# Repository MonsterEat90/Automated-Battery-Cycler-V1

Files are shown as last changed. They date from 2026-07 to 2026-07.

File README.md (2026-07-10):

# Automated-Battery-Cycler-V1
This device enabled you to test the endurance of your battery from LiFePO4, Li-On, and Li-Po (1 Cell). The size right now is for 18650 or 26650 battery cell. The load is an IRFZ44N with CC (Constant Current) and CP (Constant Power) mode.
This project is coded with PlatformIO.

Parts needed for this project:
1. ESP32 DevKit V1
2. INA219
3. ADS1115
4. TC4422
5. IRFZ44N
6. Voltage divider (R1 10K R2 10K) with 100nF ceramic cap for filter
7. NTC 10k and R2 10K (act like a Voltage divider) in series with 100nF cap for filter
8. Custom made 2 channel SPDT relay
9. 470uF electrolytic cap
10. 22uF electrolytic cap
11. MicroSD card module

# Schematic

It is best to drive the TC4422 with +12V for better control for the MOSFET and you can still give it PWN straight from the ESP32 pin. You can also change the relay with something more capable.
REMINDER!!!: Change the shunt in the INA219 according to how much current you need or use INA226 for better resolution.

# PCB

This is my PCB. Still quite basic but sufficient enough for this project.

Everything can be change according to your need. Let me know what your thought about this project.

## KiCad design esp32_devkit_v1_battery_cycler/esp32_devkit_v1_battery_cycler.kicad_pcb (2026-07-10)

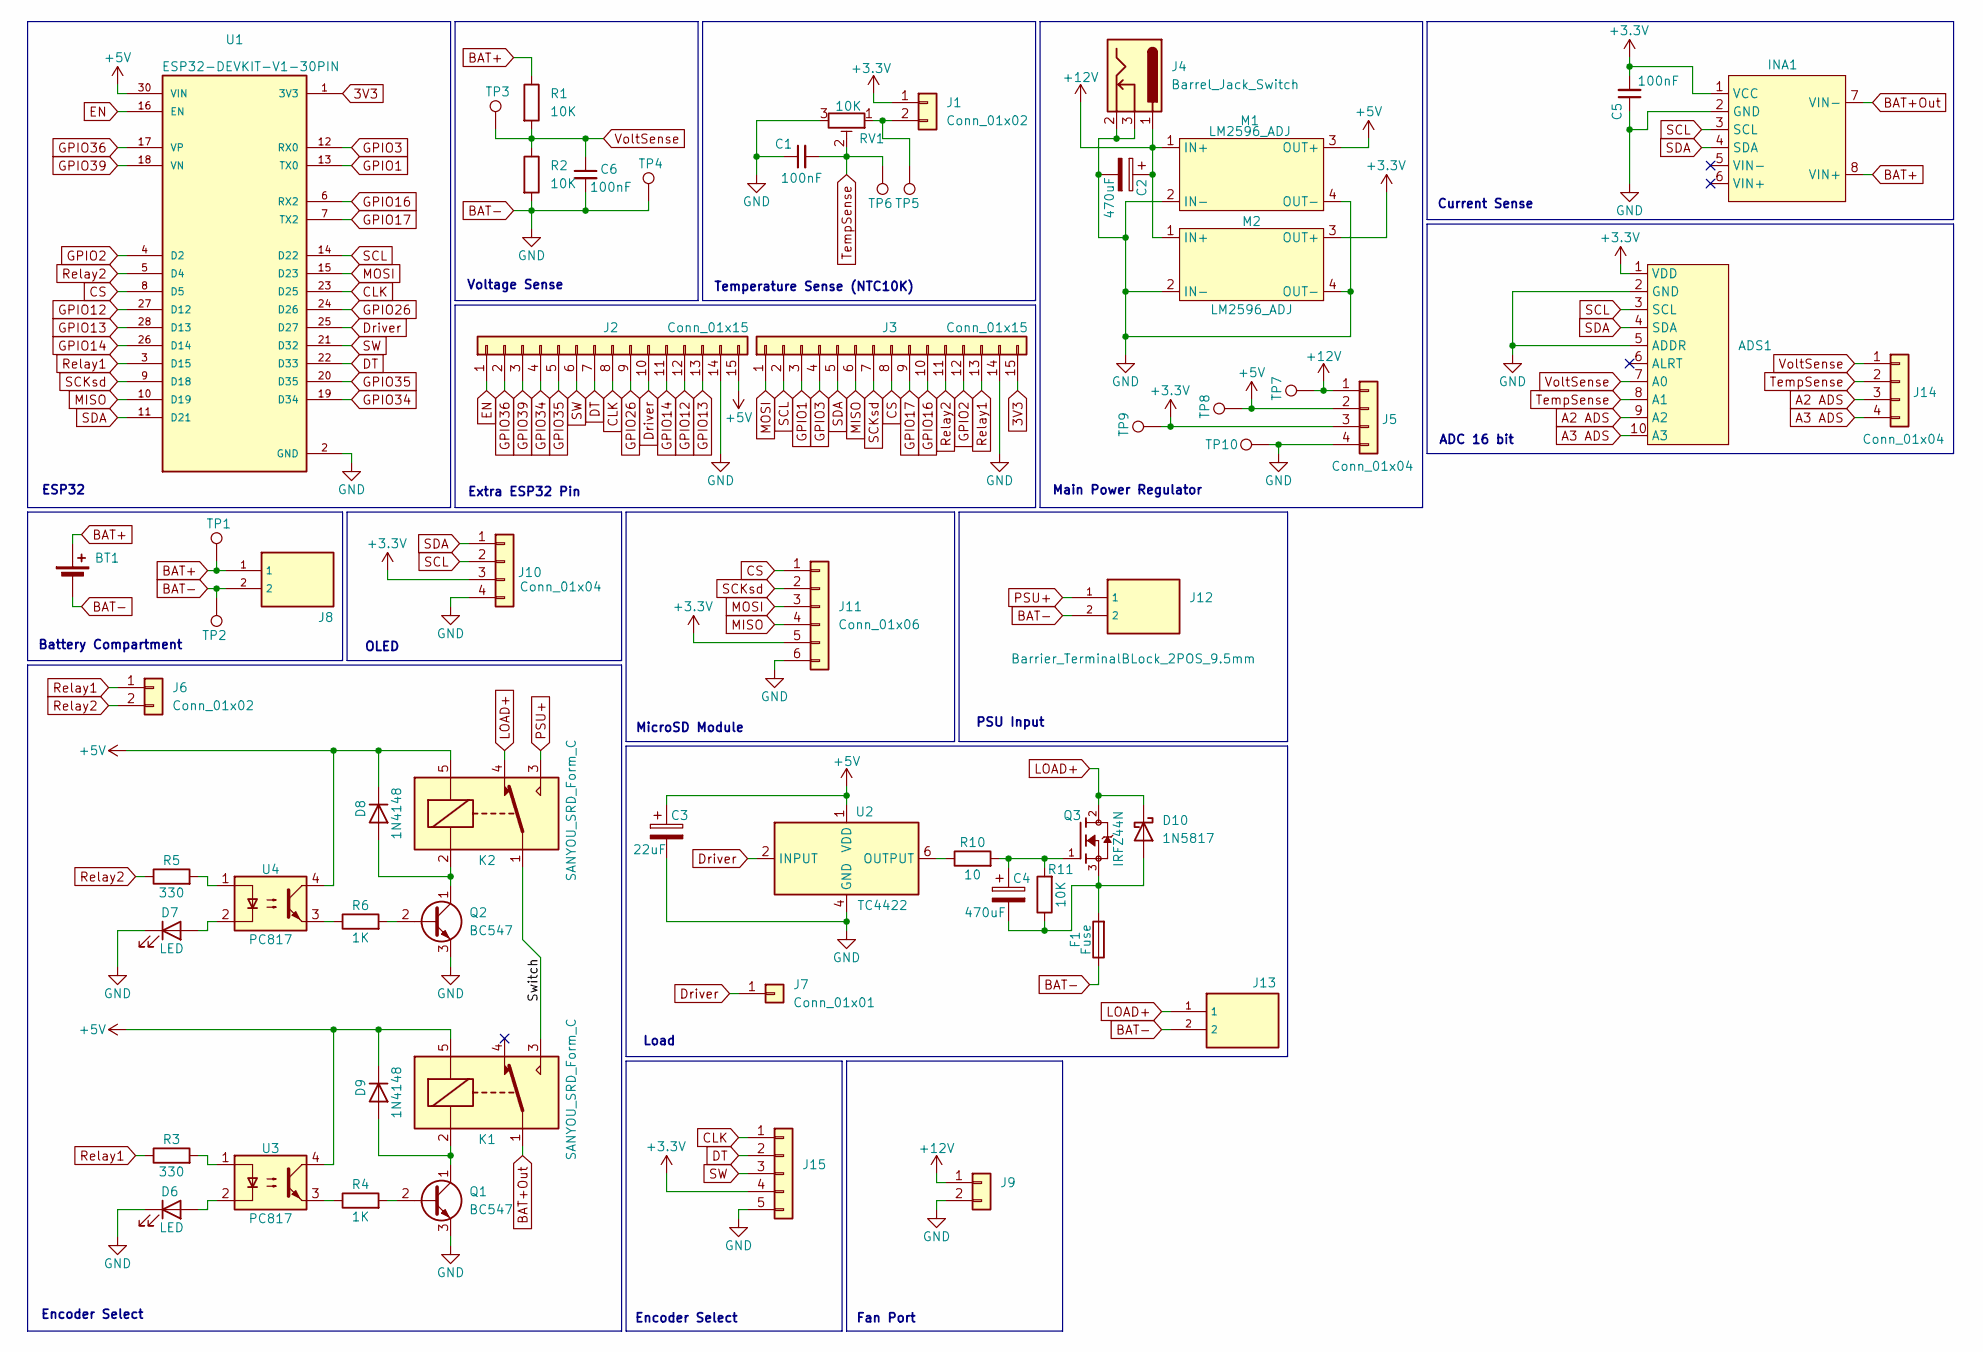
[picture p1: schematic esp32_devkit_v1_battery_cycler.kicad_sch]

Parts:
ADS1: ADS1115
BT1: Battery_Cell; 26650BatteryHolder_THT_RoundPin
C1, C5, C6: 100nF; C_Disc_D5.0mm_W2.5mm_P2.50mm
C2, C4: 470uF; CP_Radial_D8.0mm_P5.00mm
C3: 22uF; CP_Radial_D8.0mm_P5.00mm
D6, D7: LED; LED_D5.0mm
D8, D9: 1N4148; D_DO-35_SOD27_P7.62mm_Horizontal
D10: 1N5817; D_DO-41_SOD81_P10.16mm_Horizontal
F1: Fuse; Fuseholder_Clip-5x20mm_Eaton_1A5601-01_Inline_P20.80x6.76mm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
INA1: INA219
J1, J6, J9: Conn_01x02; PinHeader_1x02_P2.54mm_Vertical
J2, J3: Conn_01x15; PinHeader_1x15_P2.54mm_Vertical
J4: Barrel_Jack_Switch; BarrelJack_Horizontal
J5, J10, J14: Conn_01x04; PinHeader_1x04_P2.54mm_Vertical
J7: Conn_01x01; PinHeader_1x01_P2.54mm_Vertical
J8, J12, J13: Barrier_TerminalBLock_2POS_9.5mm; Barrier_Terminal_Block_2POS_HolePitch9.5mm
J11: Conn_01x06; PinHeader_1x06_P2.54mm_Vertical
J15: Conn_01x05; PinHeader_1x05_P2.54mm_Vertical
K1, K2: SANYOU_SRD_Form_C; Relay_SPDT_SANYOU_SRD_Series_Form_C
M1, M2: LM2596_ADJ; DCDC_StepDown_LM2596
Q1, Q2: BC547; TO-92_Inline
Q3: IRFZ44N; PARTREV 09/21/10
R1, R2: 10K; R_Axial_DIN0309_L9.0mm_D3.2mm_P12.70mm_Horizontal
R3, R5: 330; R_Axial_DIN0207_L6.3mm_D2.5mm_P10.16mm_Horizontal
R4, R6: 1K; R_Axial_DIN0207_L6.3mm_D2.5mm_P10.16mm_Horizontal
R10: 10; R_Axial_DIN0207_L6.3mm_D2.5mm_P10.16mm_Horizontal
R11: 10K; R_Axial_DIN0207_L6.3mm_D2.5mm_P10.16mm_Horizontal
RV1: 10K; Potentiometer_Runtron_RM-065_Vertical
TP1, TP2, TP3, TP4, TP5, TP6, TP7, TP8, TP9, TP10: TestPoint; TestPoint_Pad_D2.0mm
U1: ESP32-DEVKIT-V1-30PIN; ESP32DEVKITv1_30pin; PARTREV N/A
U2: TC4422; DIP-8_W7.62mm
U3, U4: PC817; DIP-4_W7.62mm

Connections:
3V3: J3.15, U1.1 (3V3)
+3.3V: ADS1.1 (VDD), C5.2, INA1.1 (VCC), J1.1, J5.3, J10.3, J11.5, J15.4, M2.3 (OUT+), TP9.1
+5V: C3.1, D8.1 (K), D9.1 (K), J2.15, J5.2, K1.5, K2.5, M1.3 (OUT+), TP8.1, U1.30 (VIN), U2.1 (VDD), U2.8 (VDD), U3.4, U4.4
+12V: C2.1, J4.1, J5.1, J9.1, M1.1 (IN+), M2.1 (IN+), TP7.1
/Switch: K1.3, K2.1
A2 ADS: ADS1.9 (A2), J14.3
A3 ADS: ADS1.10 (A3), J14.4
BAT+: BT1.1 (+), INA1.8 (VIN+), J8.1, R1.1, TP1.1
BAT+Out: INA1.7 (VIN-), K1.1
BAT-: ADS1.2 (GND), ADS1.5 (ADDR), BT1.2 (-), C1.1, C2.2, C3.2, C5.1, C6.2, D6.1 (K), D7.1 (K), F1.1, INA1.2 (GND), J2.14, J3.14, J4.2, J4.3, J5.4, J8.2, J9.2, J10.4, J11.6, J12.2, J13.2, J15.5, M1.2 (IN-), M1.4 (OUT-), M2.2 (IN-), M2.4 (OUT-), Q1.3 (E), Q2.3 (E), R2.2, RV1.3, TP2.1, TP4.1, TP10.1, U1.2 (GND), U1.29 (GND), U2.4 (GND), U2.5 (GND)
CLK: J2.8, J15.1, U1.23 (D25)
CS: J3.8, J11.1, U1.8 (D5)
DT: J2.7, J15.2, U1.22 (D33)
Driver: J2.10, J7.1, U1.25 (D27), U2.2 (INPUT)
EN: J2.1, U1.16 (EN)
GPIO1: J3.3, U1.13 (TX0)
GPIO2: J3.12, U1.4 (D2)
GPIO3: J3.4, U1.12 (RX0)
GPIO12: J2.12, U1.27 (D12)
GPIO13: J2.13, U1.28 (D13)
GPIO14: J2.11, U1.26 (D14)
GPIO16: J3.10, U1.6 (RX2)
GPIO17: J3.9, U1.7 (TX2)
GPIO26: J2.9, U1.24 (D26)
GPIO34: J2.4, U1.19 (D34)
GPIO35: J2.5, U1.20 (D35)
GPIO36: J2.2, U1.17 (VP)
GPIO39: J2.3, U1.18 (VN)
LOAD+: D10.1 (K), J13.1, K2.4, Q3.2
MISO: J3.6, J11.4, U1.10 (D19)
MOSI: J3.1, J11.3, U1.15 (D23)
unnamed: C4.1, Q3.1, R10.2, R11.2
unnamed: D6.2 (A), U3.2
unnamed: D7.2 (A), U4.2
unnamed: D8.2 (A), K2.2, Q2.1 (C)
unnamed: D9.2 (A), K1.2, Q1.1 (C)
unnamed: C4.2, D10.2 (A), F1.2, Q3.3, R11.1
unnamed: J1.2, RV1.1, TP5.1
unnamed: Q1.2 (B), R4.2
unnamed: Q2.2 (B), R6.2
unnamed: R3.2, U3.1
unnamed: R4.1, U3.3
unnamed: R5.2, U4.1
unnamed: R6.1, U4.3
unnamed: R10.1, U2.6 (OUTPUT), U2.7 (OUTPUT)
PSU+: J12.1, K2.3
Relay1: J3.13, J6.1, R3.1, U1.3 (D15)
Relay2: J3.11, J6.2, R5.1, U1.5 (D4)
SCKsd: J3.7, J11.2, U1.9 (D18)
SCL: ADS1.3 (SCL), INA1.3 (SCL), J3.2, J10.2, U1.14 (D22)
SDA: ADS1.4 (SDA), INA1.4 (SDA), J3.5, J10.1, U1.11 (D21)
SW: J2.6, J15.3, U1.21 (D32)
TempSense: ADS1.8 (A1), C1.2, J14.2, RV1.2, TP6.1
VoltSense: ADS1.7 (A0), C6.1, J14.1, R1.2, R2.1, TP3.1

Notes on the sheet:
Voltage Sense
OLED
ESP32
Encoder Select
Fan Port
Extra ESP32 Pin
ADC 16 bit
Current Sense
Temperature Sense (NTC10K)
Main Power Regulator
Load
PSU Input
MicroSD Module
Battery Compartment

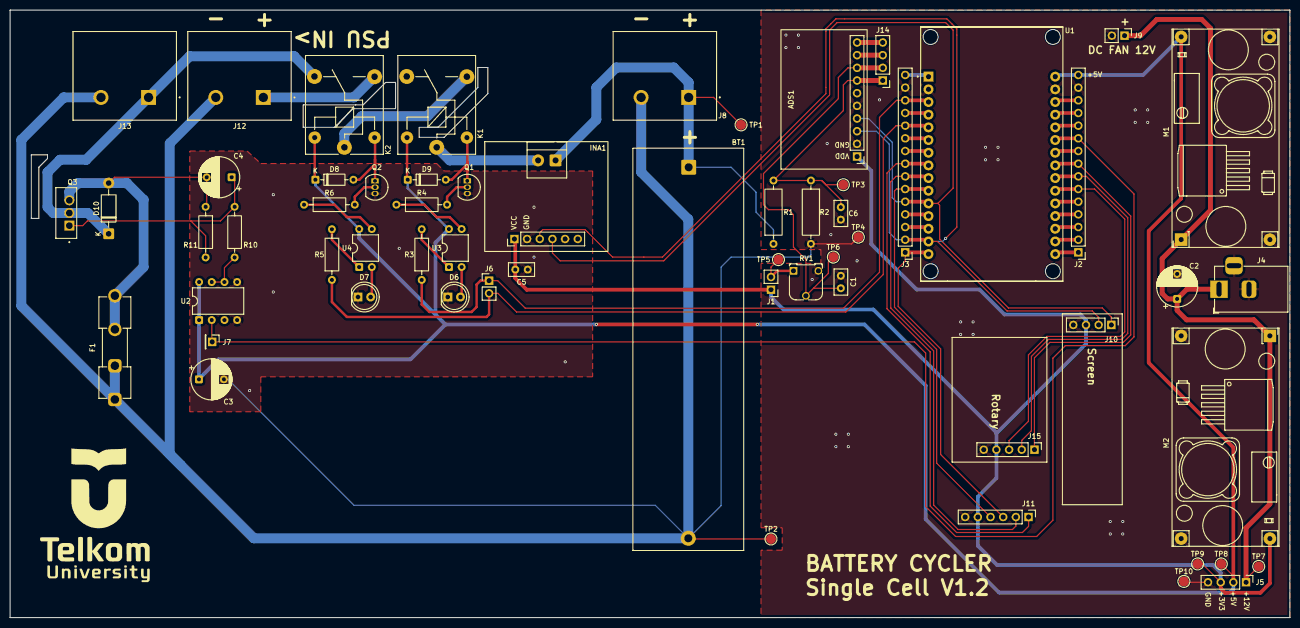
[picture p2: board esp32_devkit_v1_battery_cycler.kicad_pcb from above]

Board: 2 copper layers, 256.5 x 121.8 mm, 60 parts (0 on the bottom side), 54 nets.

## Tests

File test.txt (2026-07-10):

#include "encoder.h"
#include "types.h"

#include <Arduino.h>

#include "config.h"
#include "cycler.h"

static int lastCLK;

static uint8_t selectedItem = 0;

static UiState uiState =
    UiState::NAVIGATE;

void encoderBegin()
{
    pinMode(
        ENC_CLK_PIN,
        INPUT_PULLUP
    );

    pinMode(
        ENC_DT_PIN,
        INPUT_PULLUP
    );

    pinMode(
        ENC_SW_PIN,
        INPUT_PULLUP
    );

    lastCLK =
        digitalRead(
            ENC_CLK_PIN
        );

    Serial.println(
        "[OK] Encoder"
    );
}

static int readRotation()
{
    int movement = 0;

    int clk =
        digitalRead(
            ENC_CLK_PIN
        );

    if(clk != lastCLK)
    {
        if(
            digitalRead(
                ENC_DT_PIN
            ) != clk
        )
        {
            movement = 1;
        }
        else
        {
            movement = -1;
        }

        lastCLK = clk;
    }

    return movement;
}

static bool buttonPressed()
{
    static bool lastState = HIGH;

    bool state =
        digitalRead(
            ENC_SW_PIN
        );

    bool pressed =
        (
            lastState == HIGH &&
            state == LOW
        );

    lastState = state;

    return pressed;
}

void encoderUpdate(
    SystemData& systemData
)
{
    int move =
        readRotation();

    /*
    =====================================
    NAVIGATION MODE
    =====================================
    */

    if(
        uiState ==
        UiState::NAVIGATE
    )
    {
        if(move > 0)
        {
            if(selectedItem < 3)
            {
                selectedItem++;
            }
        }

        if(move < 0)
        {
            if(selectedItem > 0)
            {
                selectedItem--;
            }
        }

        if(buttonPressed())
        {
            if(
                selectedItem ==
                static_cast<uint8_t>(
                    MenuItem::START
                )
            )
            {
                cyclerStart(
                    systemData
                );
            }
            else
            {
                uiState =
                    UiState::EDIT;
            }
        }
    }

    /*
    =====================================
    EDIT MODE
    =====================================
    */

    else
    {
        switch(
            static_cast<MenuItem>(
                selectedItem
            )
        )
        {
            case MenuItem::CYCLE_COUNT:
            {
                systemData.settings.cycleTarget += move;

                systemData.settings.cycleTarget =
                    constrain(
                        systemData.settings.cycleTarget,
                        MIN_CYCLE_COUNT,
                        MAX_CYCLE_COUNT
                    );
                break;
            }

            case MenuItem::MODE:
            {
                if(move != 0)
                {
                    if(
                        systemData.settings.mode ==
                        DischargeMode::CONSTANT_CURRENT
                    )
                    {
                        systemData.settings.mode =
                            DischargeMode::CONSTANT_POWER;
                    }
                    else
                    {
                        systemData.settings.mode =
                            DischargeMode::CONSTANT_CURRENT;
                    }
                }
                break;
            }

            case MenuItem::SETPOINT:
            {
                /*
                Locked in V1

                CC = 3.5A
                CP = 11.2W
                */

                break;
            }

            default:
                break;
        }

        if(buttonPressed())
        {
            uiState =
                UiState::NAVIGATE;
        }
    }
}

uint8_t getSelectedMenu()
{
    return selectedItem;
}

bool isEditing()
{
    return (
        uiState ==
        UiState::EDIT
    );
}

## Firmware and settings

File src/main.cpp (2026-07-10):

#include <Arduino.h>

#include "config.h"
#include "types.h"

#include "sensors.h"
#include "relay.h"
#include "load.h"
#include "controller.h"
#include "cycler.h"
#include "safety.h"
#include "display.h"
#include "encoder.h"
#include "logger.h"

SystemData systemData;

static uint32_t sensorTimer = 0;
static uint32_t controlTimer = 0;
static uint32_t displayTimer = 0;
static uint32_t loggerTimer = 0;

void setup()
{
    Serial.begin(115200);

    Serial.println();
    Serial.println(PROJECT_NAME);
    Serial.println(FW_VERSION);

    /*Hardware*/
    sensorsBegin();
    relayBegin();
    loadBegin();

    /*Logic*/
    controllerBegin();
    cyclerBegin();
    safetyBegin();

    /*UI*/
    displayBegin();
    encoderBegin();

    /*Storage*/
    loggerBegin();

    /*Initial State*/
    systemData.state = CycleState::IDLE;
    systemData.settings.cycleTarget = 1;
    systemData.settings.mode = DischargeMode::CONSTANT_CURRENT;
}

void loop()
{
    uint32_t now = millis();

    if(now - controlTimer >= 20)
    {
        controlTimer = now;

        if(
            systemData.state ==
            CycleState::IDLE
        )
        {
            encoderUpdate(
                systemData
            );
        }
    }

    if(now - sensorTimer >= 100)
    {
        sensorTimer = now;

        sensorsUpdate(
            systemData.sensors
        );

        safetyUpdate(
            systemData
        );

        cyclerUpdate(
            systemData
        );
    }

    if(now - displayTimer >= 200)
    {
        displayTimer = now;

        if(
            systemData.state ==
            CycleState::IDLE
        )
        {
            displayMenu(
                systemData.settings,
                getSelectedMenu(),
                isEditing()
            );
        }
        else if(
            systemData.state ==
            CycleState::ERROR_STATE
        )
        {
            displayError(
                systemData
            );
        }
        else
        {
            displayRun(
                systemData
            );
        }
    }

    if(now - loggerTimer >= 1000)
    {
        loggerTimer = now;

        loggerUpdate(
            systemData
        );
    }
}

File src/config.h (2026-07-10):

#pragma once
#include <Arduino.h>

constexpr const char PROJECT_NAME[] = "Battery Cycler V1";
constexpr const char FW_VERSION[]   = "1.0.0";

#define I2C_SDA_PIN 21
#define I2C_SCL_PIN 22

#define ADS1115_ADDR 0x48
#define INA219_ADDR 0x40
#define OLED_ADDR 0x3C

#define ENC_CLK_PIN 25
#define ENC_DT_PIN 33
#define ENC_SW_PIN 32

#define RELAY_CUT_PIN 15
#define RELAY_MODE_PIN 4

#define LOAD_PWM_PIN 27

#define SD_CS_PIN 5

#define ADC_BATTERY_CHANNEL 0
#define ADC_TEMPERATURE_CHANNEL 1

#define SCREEN_WIDTH 128
#define SCREEN_HEIGHT 32

/*
==================================================
VOLTAGE DIVIDER
==================================================
Battery ---- 10k ---- ADC ---- 10k ---- GND

Ratio = (R1 + R2) / R2 = 2.0
==================================================
*/
constexpr float VOLTAGE_R1 = 9930.0f;
constexpr float VOLTAGE_R2 = 9920.0f;

constexpr float VOLTAGE_DIVIDER_RATIO =
    (VOLTAGE_R1 + VOLTAGE_R2) / VOLTAGE_R2;

/*
==================================================
NTC PARAMETERS
==================================================
10k NTC
Beta = 3950
==================================================
*/
constexpr float NTC_BETA = 3950.0f;
constexpr float NTC_R0 = 9930.0f;
constexpr float NTC_T0 = 25.0f;

constexpr float NTC_FIXED_RESISTOR = 10000.0f;

/*
==================================================
BATTERY LIMITS
==================================================
*/
constexpr float CHARGE_STOP_VOLTAGE = 3.65f;
constexpr float CHARGE_MAX_VOLTAGE  = 3.70f;

constexpr float DISCHARGE_STOP_VOLTAGE = 2.30f;
constexpr float DISCHARGE_MIN_VOLTAGE  = 2.10f;

constexpr float MAX_TEMPERATURE = 75.0f;
constexpr float MAX_CURRENT = 5.0f;

constexpr float CC_DISCHARGE_CURRENT = 3.5f;
constexpr float CP_DISCHARGE_POWER = 11.2f;

constexpr uint16_t MIN_CYCLE_COUNT = 1;
constexpr uint16_t MAX_CYCLE_COUNT = 4000;

constexpr float MIN_CC_CURRENT = 0.5f;
constexpr float MAX_CC_CURRENT = 5.0f;
constexpr float CC_STEP = 0.1f;

constexpr float MIN_CP_POWER = 1.0f;
constexpr float MAX_CP_POWER = 12.0f;
constexpr float CP_STEP = 0.1f;

/*
==================================================
CHARGE TERMINATION
==================================================
*/

constexpr float CHARGE_FULL_VOLTAGE = 3.60f;

constexpr float CHARGE_FULL_CURRENT = 0.20f;

constexpr uint32_t CHARGE_FULL_DELAY_MS = 30000;   // 30 seconds

/*
==================================================
LOGGING
==================================================
*/
constexpr uint32_t LOG_INTERVAL_MS = 1000;
constexpr const char LOG_FILENAME[] = "/cycler.csv";

/*
==================================================
STATE MACHINE TIMING
==================================================
*/
constexpr uint32_t SENSOR_UPDATE_MS = 100;
constexpr uint32_t DISPLAY_UPDATE_MS = 200;
constexpr uint32_t CONTROL_UPDATE_MS = 20;

/*
==================================================
LOAD PWM
==================================================
*/
constexpr uint8_t PWM_CHANNEL = 0;
constexpr uint32_t PWM_FREQUENCY = 20000;
constexpr uint8_t PWM_RESOLUTION = 10;
constexpr uint16_t PWM_MIN = 0;
constexpr uint16_t PWM_MAX = 1023;

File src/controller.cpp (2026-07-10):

#include "controller.h"

#include <Arduino.h>

#include "config.h"
#include "load.h"

static uint16_t pwmOutput = 0;

void controllerBegin()
{
    pwmOutput = 0;

    loadOff();

    Serial.println(
        "[OK] Controller Ready"
    );
}

void controllerReset()
{
    pwmOutput = 0;

    loadOff();
}

uint16_t getControllerPWM()
{
    return pwmOutput;
}

/*
==================================================
CONSTANT CURRENT
==================================================
*/

static void controlCC(
    float targetCurrent,
    float measuredCurrent
)
{
    float error =
        targetCurrent -
        measuredCurrent;

    if(error > 0.20f)
    {
        pwmOutput += 8;
    }
    else if(error > 0.05f)
    {
        pwmOutput += 2;
    }
    else if(error < -0.20f)
    {
        pwmOutput -= 8;
    }
    else if(error < -0.05f)
    {
        pwmOutput -= 2;
    }
}

/*
==================================================
CONSTANT POWER
==================================================
*/

static void controlCP(
    float targetPower,
    float measuredPower
)
{
    float error =
        targetPower -
        measuredPower;

    if(error > 0.50f)
    {
        pwmOutput += 8;
    }
    else if(error > 0.10f)
    {
        pwmOutput += 2;
    }
    else if(error < -0.50f)
    {
        pwmOutput -= 8;
    }
    else if(error < -0.10f)
    {
        pwmOutput -= 2;
    }
}

/*
==================================================
UPDATE
==================================================
*/

void controllerUpdate(
    const SensorData& sensors,
    const TestSettings& settings
)
{
    switch(settings.mode)
    {
        case DischargeMode::CONSTANT_CURRENT:
        {
            controlCC(
                settings.ccCurrent,
                sensors.current
            );
            break;
        }

        case DischargeMode::CONSTANT_POWER:
        {
            controlCP(
                settings.cpPower,
                sensors.power
            );
            break;
        }
    }

    pwmOutput =
        constrain(
            pwmOutput,
            PWM_MIN,
            PWM_MAX
        );

    setLoadPWM(
        pwmOutput
    );
}

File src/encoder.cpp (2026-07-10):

#include "encoder.h"
#include "types.h"

#include <Arduino.h>
#include <RotaryEncoder.h>

#include "config.h"
#include "cycler.h"

static RotaryEncoder encoder(
    ENC_CLK_PIN,
    ENC_DT_PIN,
    RotaryEncoder::LatchMode::TWO03
);

static int lastPosition = 0;

static uint8_t selectedItem = 0;

static UiState uiState =
    UiState::NAVIGATE;

void encoderBegin()
{
    pinMode(
        ENC_SW_PIN,
        INPUT_PULLUP
    );

    encoder.setPosition(0);

    lastPosition = 0;

    Serial.println(
        "[OK] Encoder"
    );
}

static int readRotation()
{
    encoder.tick();

    int position =
        encoder.getPosition();

    int movement =
        position -
        lastPosition;

    lastPosition =
        position;

    return movement;
}

static bool buttonPressed()
{
    static bool lastState = HIGH;
    static uint32_t lastDebounce = 0;

    bool state =
        digitalRead(
            ENC_SW_PIN
        );

    bool pressed = false;

    if(
        millis() - lastDebounce > 50
    )
    {
        if(
            lastState == HIGH &&
            state == LOW
        )
        {
            pressed = true;
            lastDebounce = millis();
        }
    }

    lastState = state;

    return pressed;
}

void encoderUpdate(
    SystemData& systemData
)
{
    encoder.tick();
    int move =
        readRotation();

    /*
    =====================================
    NAVIGATION MODE
    =====================================
    */

    if(
        uiState ==
        UiState::NAVIGATE
    )
    {
        if(move > 0)
        {
            if(selectedItem < 3)
            {
                selectedItem++;
            }
        }

        if(move < 0)
        {
            if(selectedItem > 0)
            {
                selectedItem--;
            }
        }

        if(buttonPressed())
        {
            if(
                selectedItem ==
                static_cast<uint8_t>(
                    MenuItem::START
                )
            )
            {
                cyclerStart(
                    systemData
                );
            }
            else
            {
                uiState =
                    UiState::EDIT;
            }
        }
    }

    /*
    =====================================
    EDIT MODE
    =====================================
    */

    else
    {
        switch(
            static_cast<MenuItem>(
                selectedItem
            )
        )
        {
            case MenuItem::CYCLE_COUNT:
            {
                systemData.settings.cycleTarget += move;

                systemData.settings.cycleTarget =
                    constrain(
                        systemData.settings.cycleTarget,
                        MIN_CYCLE_COUNT,
                        MAX_CYCLE_COUNT
                    );
                break;
            }

            case MenuItem::MODE:
            {
                if(move != 0)
                {
                    if(
                        systemData.settings.mode ==
                        DischargeMode::CONSTANT_CURRENT
                    )
                    {
                        systemData.settings.mode =
                            DischargeMode::CONSTANT_POWER;
                    }
                    else
                    {
                        systemData.settings.mode =
                            DischargeMode::CONSTANT_CURRENT;
                    }
                }
                break;
            }

            case MenuItem::SETPOINT:
            {
                if(move != 0)
                {
                    if(
                        systemData.settings.mode ==
                        DischargeMode::CONSTANT_CURRENT
                    )
                    {
                    systemData.settings.ccCurrent +=
                        move * CC_STEP;

                    systemData.settings.ccCurrent =
                        constrain(
                            systemData.settings.ccCurrent,
                            MIN_CC_CURRENT,
                            MAX_CC_CURRENT
                        );
                    }
                    else
                    {
                        systemData.settings.cpPower +=
                            move * CP_STEP;

                        systemData.settings.cpPower =
                            constrain(
                                systemData.settings.cpPower,
                                MIN_CP_POWER,
                                MAX_CP_POWER
                            );
                    }
                }

                break;
            }

            default:
                break;
        }

        if(buttonPressed())
        {
            uiState =
                UiState::NAVIGATE;
        }
    }
}

uint8_t getSelectedMenu()
{
    return selectedItem;
}

bool isEditing()
{
    return (
        uiState ==
        UiState::EDIT
    );
}
